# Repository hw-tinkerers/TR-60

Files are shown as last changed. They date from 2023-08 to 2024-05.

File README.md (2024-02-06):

# TR-60
TR-60 is a 60% custom mechanical keyboard PCB that is inspired by the  [bakeneko](https://github.com/kkatano/bakeneko-60) PCB but adds a couple of improvements to it.

1. TR-60 adds BLE support to the PCB so that it can be used wirelessly.
2. Add tray mount compatible holes to be used with keyboard cases like [Salvation](https://ilumkb.com/products/wilba-tech-salvation-keyboard)

TR-60 stands for typewriter-60.

The repository contains the KICAD files of the keyboard PCB design with an nRF chip and this PCB is one of the first PCB to be built around the nRF52840 bare chip and not around any module.

<strong>Front View (Rendering)</strong>

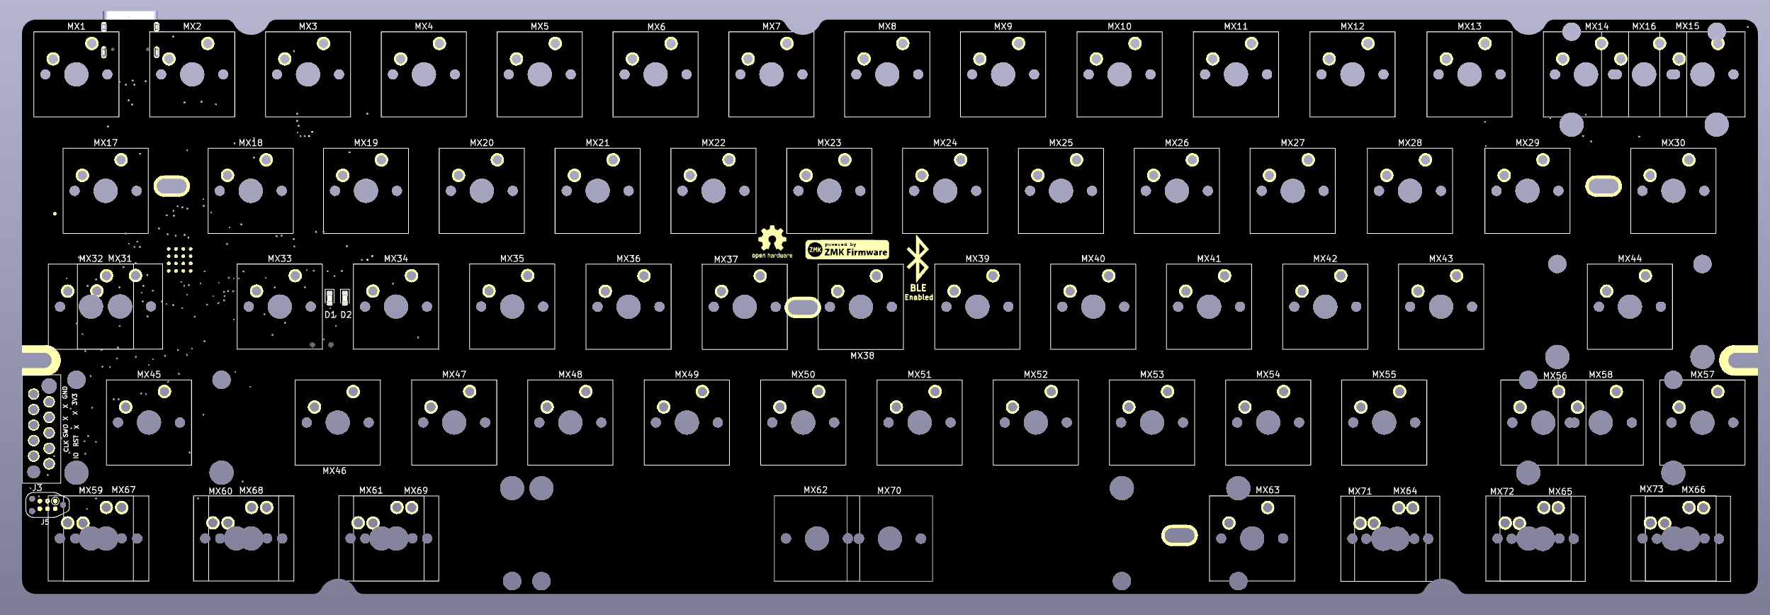
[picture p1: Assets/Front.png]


<strong>Back View (Rendering)</strong>

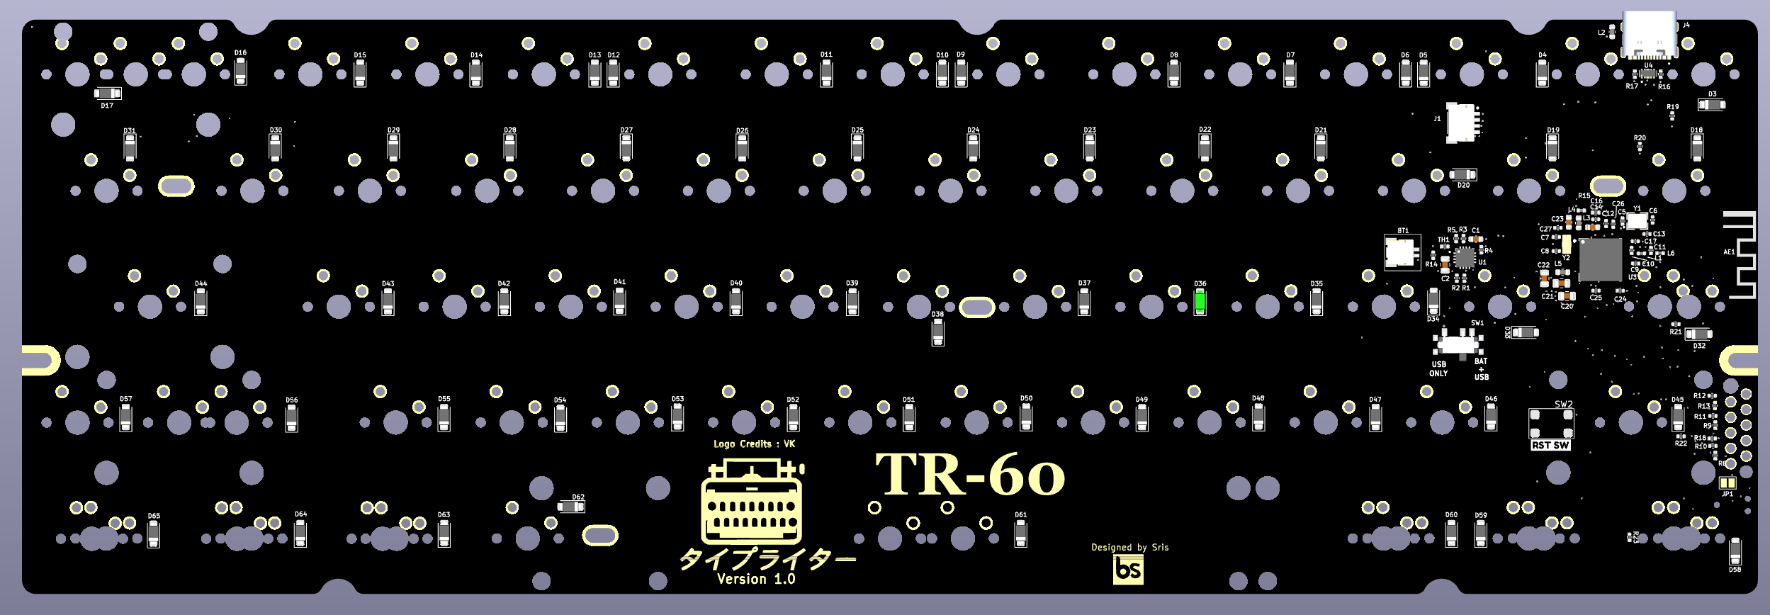
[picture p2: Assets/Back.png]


<strong>Front View of PCB</strong>.

plot

<strong>Back View of PCB</strong>.

plot

<strong>Front View fully assembled with keycaps</strong>.

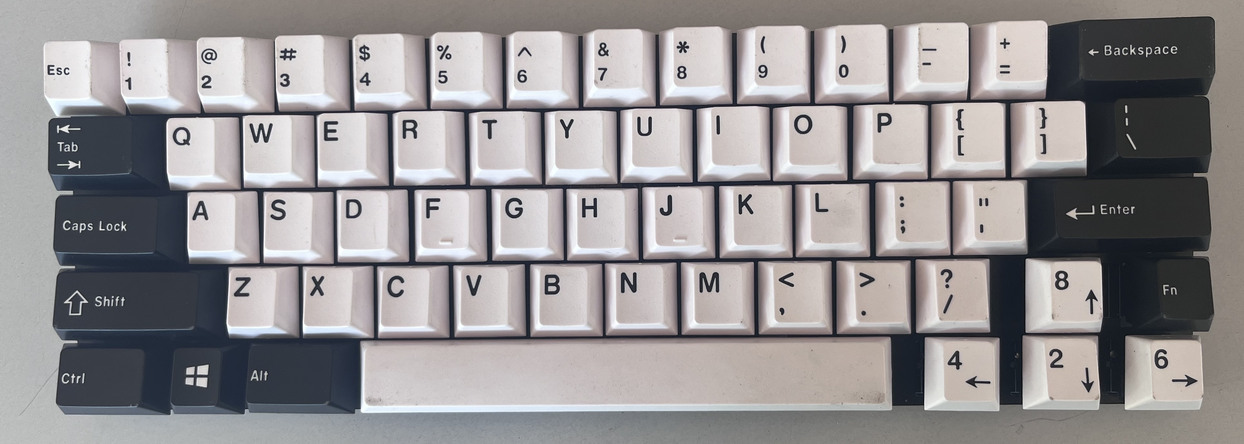
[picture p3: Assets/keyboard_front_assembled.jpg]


<strong>Back View fully assembled with battery</strong>.

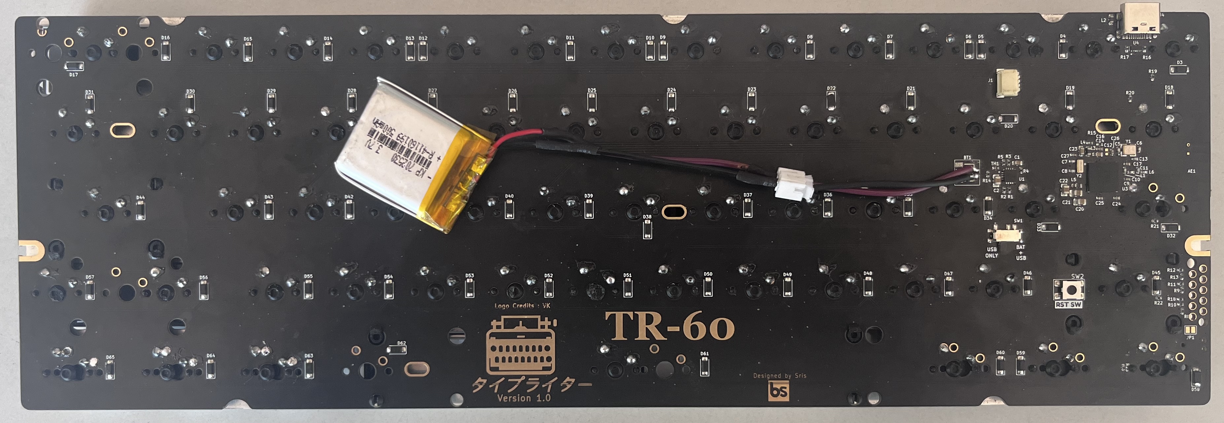
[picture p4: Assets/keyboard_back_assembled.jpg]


<strong>Fully assembled with Bakeneko case</strong>.

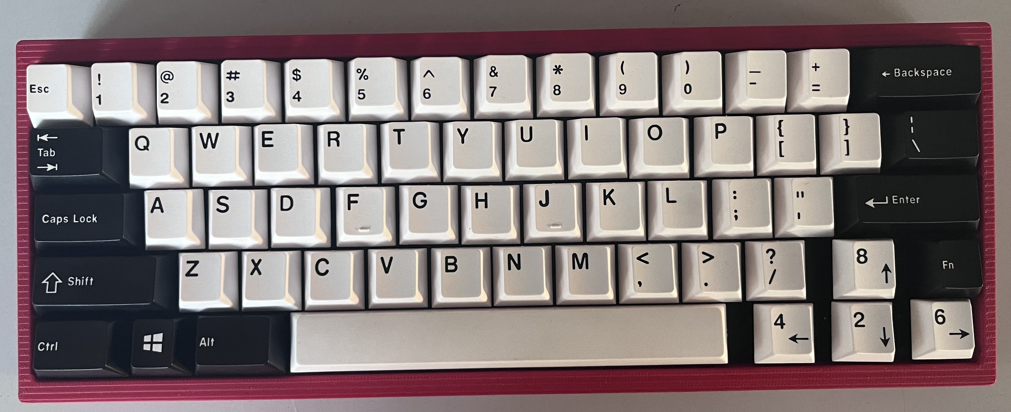
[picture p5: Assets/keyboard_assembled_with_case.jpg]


The PCB is designed in such a way that is compatible with both nRF52840 and nRF52833 MCUs as they have the same pinouts and the NC pins on nRF53833 are being used in nRF52840 making it compatible with both MCUs to mitigate supply shortage problems.

The PCB has a board antenna for BLE and an onboard charger chip BQ24075 (also compatible with BQ24073 and BQ24074) with a JST (1mm) connector for lipo battery (But the 1mm JST connector is non-conventional and will be changed to a more mainstream connector with 2.54mm pitch with which most lipo batteries are shipped). A lipo battery of 200-1000mAh can be used with the PCB. (Note: Tested only with 300mAH battery, but up to 1000mAH should not be a problem. But do it at your own risk)

The PCB has a SWD 10-pin debug connector compatible with [tag-connect](https://www.tag-connect.com/product/tc2050-idc-nl-050-all) 10-pin debug connector for flashing firmware.
The board also supports an Adafruit-UF2 bootloader to upload firmware through the USB type-C connector (If a PCB is bought from us). You can find how to build and flash the UF2 bootloader to the board in an upcoming tutorial. (still under making)

You can also order your PCB from JLC PCB with the Gerber and BOM files provided in the repository in the production folder. The video guide on how to order from JLC will be up soon.

The board supports [ZMK](https://zmk.dev/) firmware for USB and BLE connectivity. The hardware definition for the nRF52 chip is written and the guide to customize the keymap to customize the keys for the keyboard can be found below. 

The firmware can be built directly on GitHub using GitHub actions and also a local toolchain can be set up on your computer to build firmware. Both the links can be found below.

1. [Local Toolchain setup](https://github.com/hw-tinkerers/zmk)
2. [Github Actions](https://github.com/hw-tinkerers/tr60-zmk-config)

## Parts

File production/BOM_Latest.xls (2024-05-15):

Designator | Footprint | Qty | Value | LCSC Part Number | MFR PN
BT1 | keyboard:JST-2-pin | 1 | Lipo cell | C160402 | SM02B-SRSS-TB(LF)(SN)
C1, C14, C23 | keyboard:C_0603_1608Metric | 3 | 1uF | C1592 | CL10A105KO8NNNC
C2, C20, C21, C22 | keyboard:C_0805_2012Metric | 4 | 4u7F | C1779 | CL21A475KAQNNNE
C5, C6, C7, C8 | keyboard:C_0402_1005Metric | 4 | 8pF | C962144 | AC0402CRNPO9BN8R0
C9 | keyboard:C_0402_1005Metric | 1 | 820pF | C107031 | CC0402KRX7R9BB821
C10 | keyboard:C_0402_1005Metric | 1 | 1pF | C309455 | CC0402BRNPO9BN1R0
C11 | keyboard:C_0402_1005Metric | 1 | 1.2pF | C327292 | CC0402BRNPO9BN1R2
C13 | keyboard:C_0402_1005Metric | 1 | 100pF | C106200 | CC0402JRNPO9BN101
C16, C17, C24, C25, C26, C27 | keyboard:C_0402_1005Metric | 6 | 100nF | C1525 | CL05B104KO5NNNC
D1 | keyboard:LED_0603_1608Metric | 1 | LED | C965799 | XL-1608SURC-06
D2 | keyboard:LED_0603_1608Metric | 1 | LED | C193191 | ORH-B36G
D3, D4, D5, D6, D7, D8, D9, D10, D11, D12, D13, D14, D15, D16, D17, D18, D19, D20, D21, D22, D23, D24, D25, D26, D27, D28, D29, D30, D31, D32, D33, D34, D35, D36, D37, D38, D39, D40, D41, D42, D43, D44, D45, D46, D47, D48, D49, D50, D51, D52, D53, D54, D55, D56, D57, D58, D59, D60, D61, D62, D63, D64, D65 | keyboard:D_SOD-123 | 63 | 1N4148W | C81598 | 1N4148W
J1 | keyboard:JST-4-pin | 1 | JST-4-pin | C160404 | SM04B-SRSS-TB(LF)(SN)
J4 | keyboard:tyye_c_connector | 1 | TYPE-C-31-M12_13 | C165948 | TYPE-C-31-M-12
L1 | keyboard:L_0402_1005Metric | 1 | 4.7nH | C136252 | MLK1005S4N7ST000
L2 | keyboard:L_0603_1608Metric | 1 | 60R@100MHz | C307775 | MPZ1608S600ATDH5
L3, L5 | keyboard:L_0603_1608Metric | 2 | 10uH | C3911082 | LQM18DZ100M70L
L4 | keyboard:L_0402_1005Metric | 1 | 15nH | C86059 | LQG15HS15NJ02D
L6 | keyboard:L_0402_1005Metric | 1 | 2.2nH | C5201668 | BSCH001005052N2SCS
R1, R2, R3, R4 | keyboard:R_0402_1005Metric | 4 | 1k2 | C138040 | RC0402FR-071K2L
R5, R16, R17 | keyboard:R_0402_1005Metric | 3 | 5k1 | C105872 | RC0402FR-075K1L
R8, R9, R13, R14,R15, R18 | keyboard:R_0402_1005Metric | 6 | 10k | C60490 | RC0402FR-0710KL
R19, R20, R21, R22, R23 | keyboard:R_0402_1005Metric | 5 | 0E | C346504 | HCJ0402ZT0R00
R10, R11, R12 | keyboard:R_0402_1005Metric | 3 | 22E | C114765 | RC0402FR-0722RL
SW1 | keyboard:SPDT | 1 | MK-12C02-G025 | C778186 | MK-12C02-G025
SW2 | keyboard:RST_SW | 1 | Reset Switch | C388640 | TS-1127-C
TH1 | keyboard:R_0402_1005Metric | 1 | 10k | C95939 | SDNT1005X103F3950FTF
U1 | keyboard:QFN-16 | 1 | BQ24073RGTR | C15220 | BQ24073RGTR
U3 | keyboard:aqfn73 | 1 | nRF52840-QIAA-R | C190794 | nRF52840-QIAA-R
U4 | keyboard:USON-10 | 1 | TPD4E05U06DQAR | C138714 | TPD4E05U06DQAR
Y1 | keyboard:SMD-4_crystal | 1 | 32MHz | C2149125 | 3TJ432000HYFBC
Y2 | keyboard:SMD-2_crystal | 1 | 32.768kHz | C97605 | SC-32S32.768kHz20PPM9pF

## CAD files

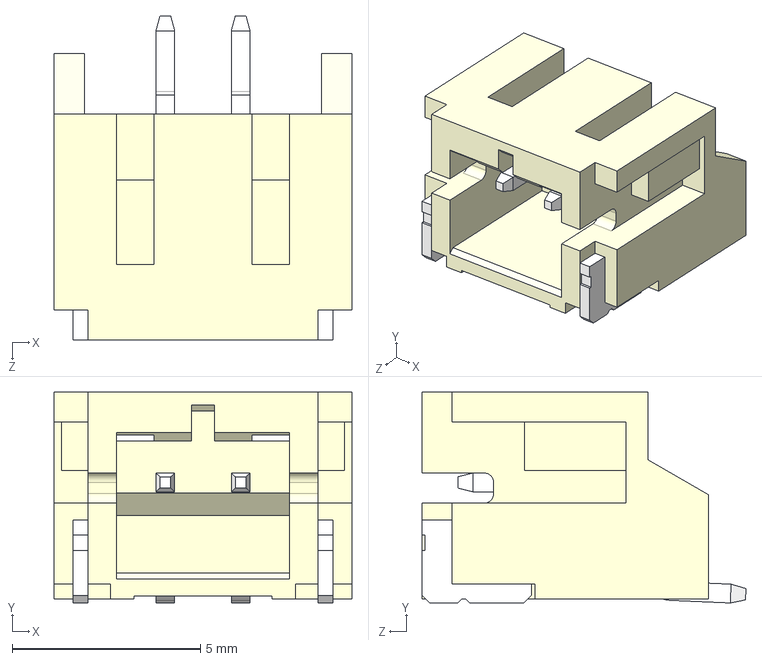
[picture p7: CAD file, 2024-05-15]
3d-models/JST-2pin.STEP
7.90 x 5.60 x 8.60 mm

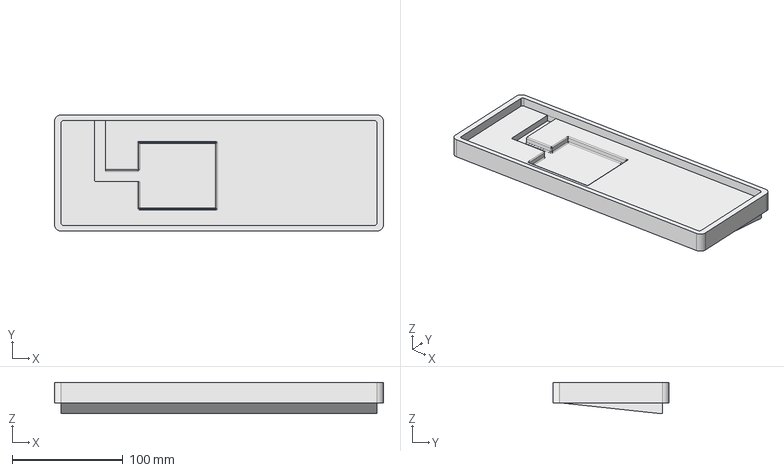
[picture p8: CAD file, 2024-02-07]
Keyboard_60-Body.step
297.0 x 105.0 x 28.4 mm

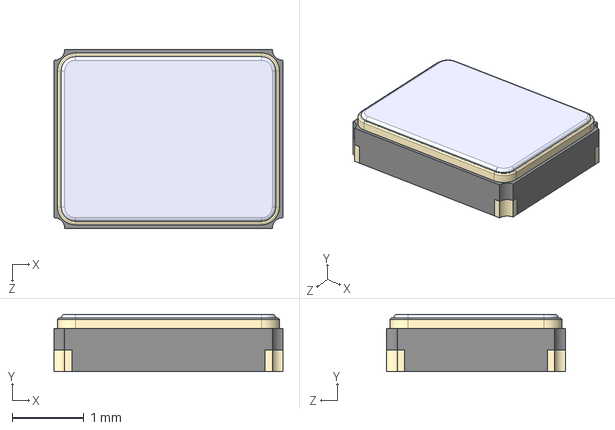
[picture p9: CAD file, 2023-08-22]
3d-models/SMD-4_crystal.STEP
3.20 x 0.8 x 2.50 mm

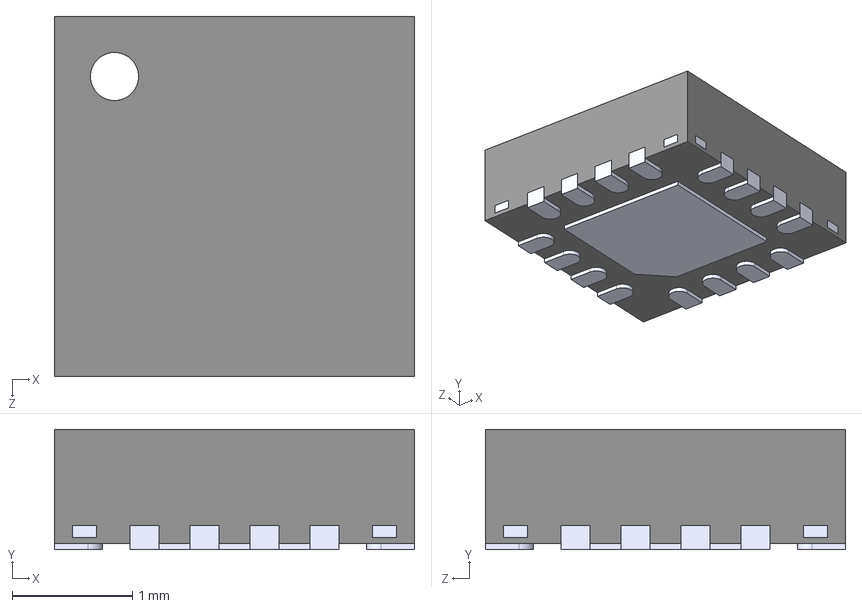
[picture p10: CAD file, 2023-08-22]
3d-models/VQFN-16.STEP
3.00 x 1.00 x 3.00 mm

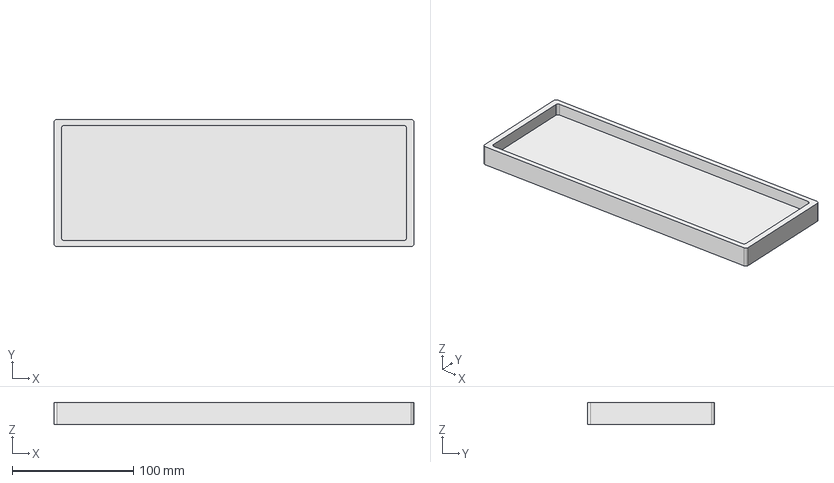
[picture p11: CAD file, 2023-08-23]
TR-60.FCStd
297.0 x 105.0 x 18.5 mm

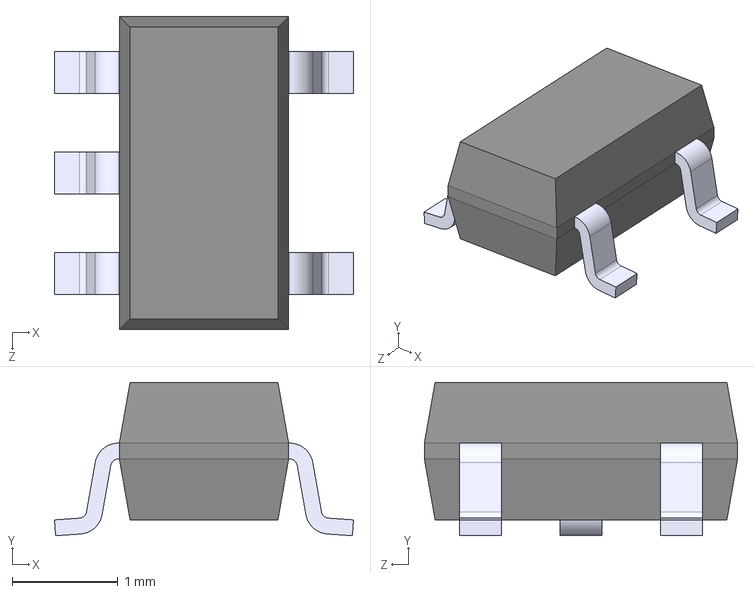
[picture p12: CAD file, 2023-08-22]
3d-models/SOT-23-5.STEP
2.82 x 1.45 x 2.96 mm

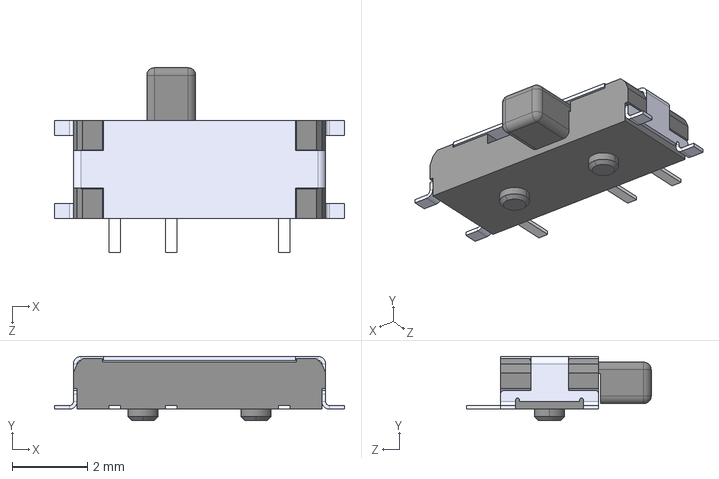
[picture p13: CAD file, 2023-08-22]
3d-models/SPDT.step
7.70 x 1.70 x 4.90 mm

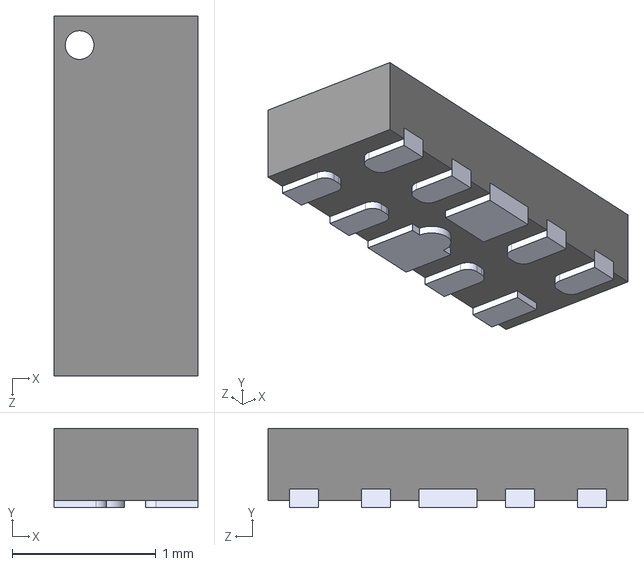
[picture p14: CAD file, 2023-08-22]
3d-models/USON-10.STEP
1.00 x 0.55 x 2.50 mm

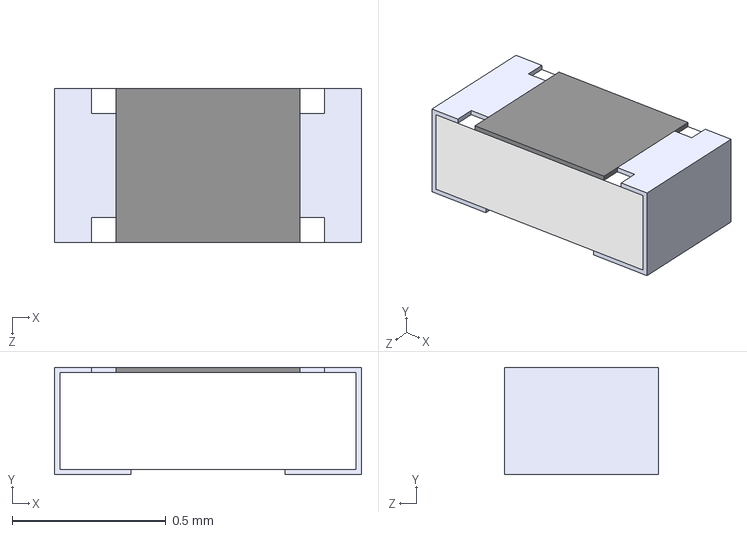
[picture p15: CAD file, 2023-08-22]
3d-models/R_0402.STEP
1 x 0.35 x 0.5 mm

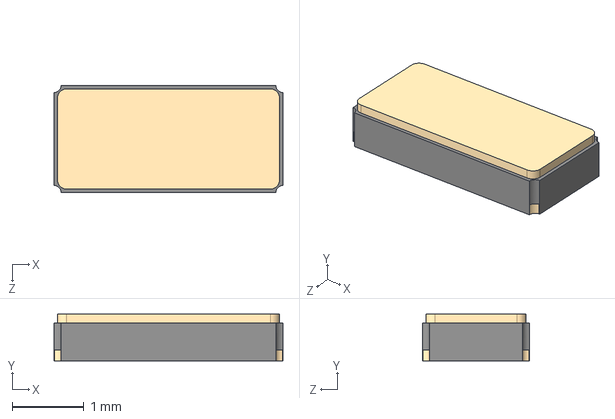
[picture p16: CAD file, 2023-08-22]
3d-models/SMD-2.step
3.20 x 0.65 x 1.50 mm

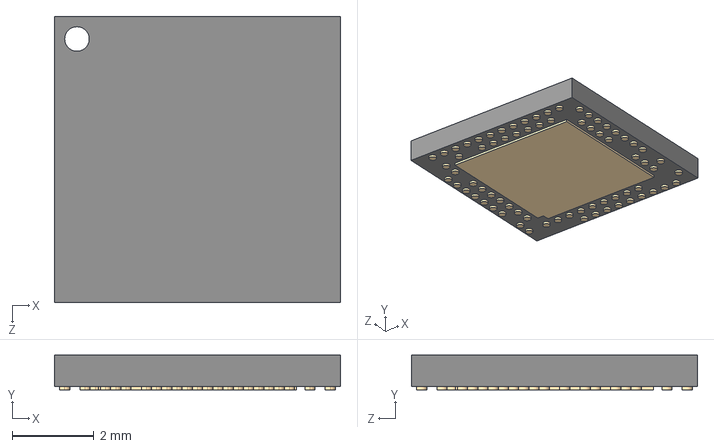
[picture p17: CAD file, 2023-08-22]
3d-models/AQFN-73.STEP
7.00 x 0.85 x 7.00 mm

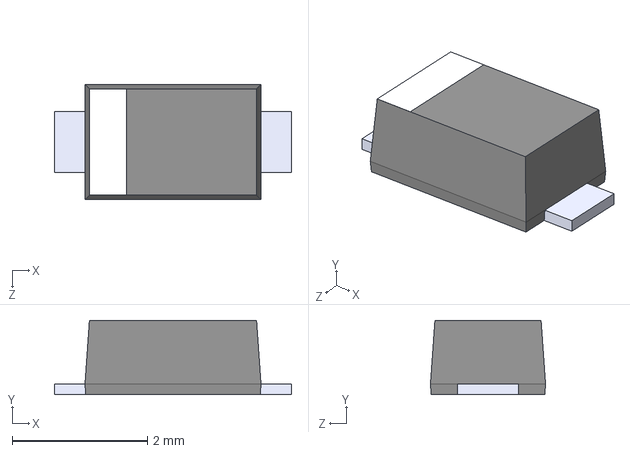
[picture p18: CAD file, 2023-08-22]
3d-models/SOD-123.STEP
3.50 x 1.10 x 1.70 mm

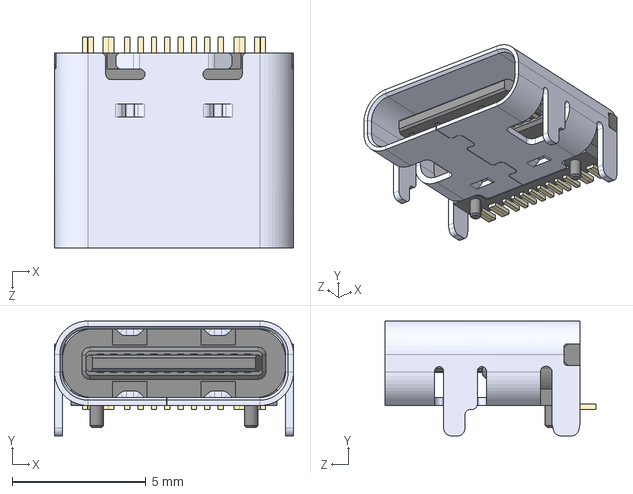
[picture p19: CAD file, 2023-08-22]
3d-models/type_c_connector.STEP
8.94 x 4.30 x 7.90 mm

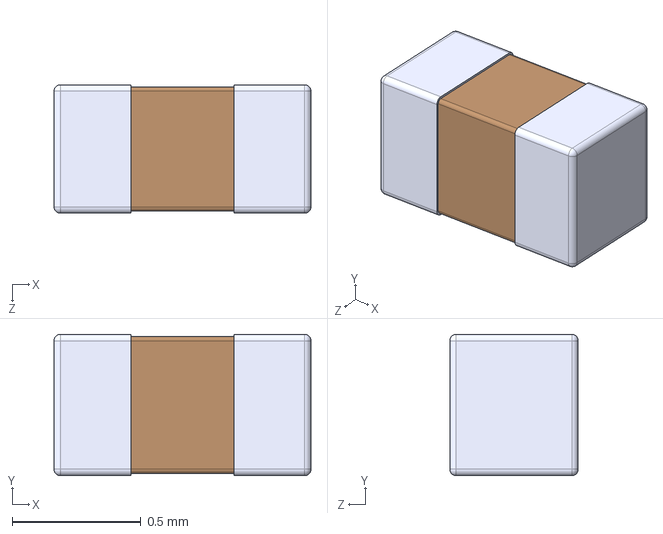
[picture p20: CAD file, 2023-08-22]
3d-models/C_0402.STEP
1.00 x 0.55 x 0.5 mm

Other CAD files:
Keyboard_60.FCStd
3d-models/C_0805.STEP
3d-models/JST-4pin.STEP
3d-models/C_0603.STEP
3d-models/LED_0603.STEP

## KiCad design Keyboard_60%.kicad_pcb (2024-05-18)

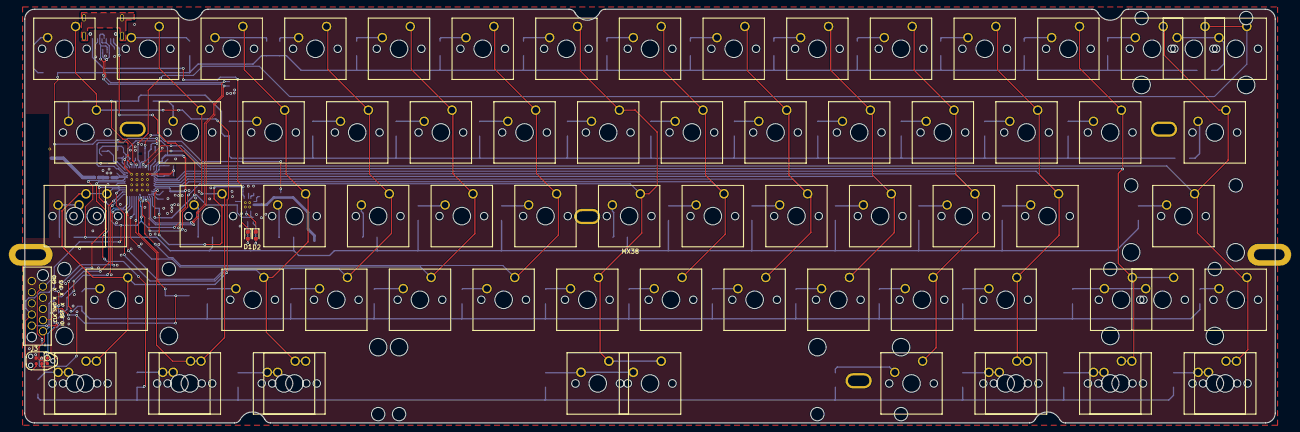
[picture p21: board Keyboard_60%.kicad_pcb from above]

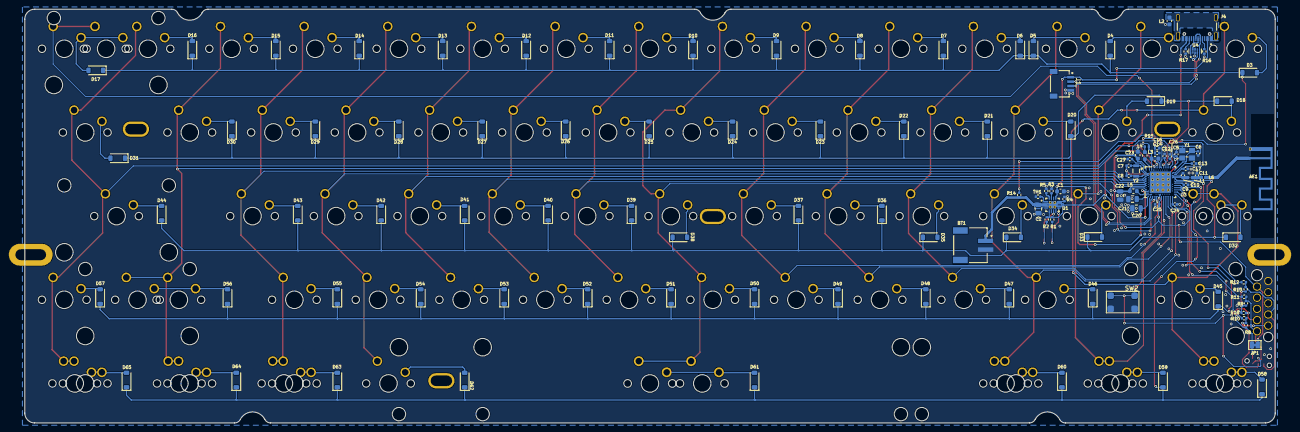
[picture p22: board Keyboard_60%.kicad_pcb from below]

Board: 2 copper layers, 284.7 x 94.2 mm, 200 parts (119 on the bottom side), 126 nets.

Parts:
AE1: Antenna_Shield; BLE_ANTENNA
BT1: Lipo cell; JST-2-pin
C1, C14, C23: 1uF; C_0603_1608Metric
C2, C20, C21, C22: 4u7F; C_0805_2012Metric
C5, C6, C7, C8: 8pF; C_0402_1005Metric
C9: 820pF; C_0402_1005Metric
C10: 1pF; C_0402_1005Metric
C11: 1.2pF; C_0402_1005Metric
C12: DNP; C_0402_1005Metric
C13: 100pF; C_0402_1005Metric
C16, C17, C24, C25, C26, C27: 100nF; C_0402_1005Metric
D1, D2: LED; LED_0603_1608Metric
D3, D4, D5, D6, D7, D8, D9, D10, D11, D12, D13, D14, D15, D16, D17, D18, D19, D20, D21, D22, D23, D24, D25, D26, D27, D28, D29, D30, D31, D32, D33, D34, D35, D36, D37, D38, D39, D40, D41, D42, D43, D44, D45, D46, D47, D48, D49, D50, D51, D52, D53, D54, D55, D56, D57, D58, D59, D60, D61, D62, D63, D64, D65: 1N4148W; D_SOD-123
J1: JST-4-pin
J3: Prog_conn; DB_CONN
J4: TYPE-C-31-M12_13; tyye_c_connector
J5: Tag connect TC2030-CTX; TC2030-IDC-NL
JP1: SolderJumper; SolderBridge
L1: 4.7nH; L_0402_1005Metric
L2: 60R@100MHz; L_0603_1608Metric
L3, L5: 10uH; L_0603_1608Metric
L4: 15nH; L_0402_1005Metric
L6: 2.2nH; L_0402_1005Metric
MX1, MX2, MX3, MX4, MX5, MX6, MX7, MX8, MX9, MX10, MX11, MX12, MX13, MX14, MX15, MX18, MX19, MX20, MX21, MX22, MX23, MX24, MX25, MX26, MX27, MX28, MX29, MX33, MX34, MX35, MX36, MX37, MX38, MX39, MX40, MX41, MX42, MX43, MX46, MX47, MX48, MX49, MX50, MX51, MX52, MX53, MX54, MX55, MX57, MX68, MX72: 1u; SW_Cherry_MX_1.00u_PCB
MX16: 2u; SW_Cherry_MX_2.00u_PCB
MX17, MX30, MX67, MX69, MX71, MX73: 1.5u; SW_Cherry_MX_1.50u_PCB
MX31, MX56: 1.75u; SW_Cherry_MX_1.75u_PCB
MX32, MX59, MX60, MX61, MX63, MX64, MX65, MX66: 1.25u; SW_Cherry_MX_1.25u_PCB
MX44, MX45: 2.25u; SW_Cherry_MX_2.25u_PCB
MX58: 2.75u; SW_Cherry_MX_2.75u_PCB
MX62: 6.25u; SW_Cherry_MX_6.25u_PCB
MX70: 7u; SW_Cherry_MX_7.00u_PCB
R1, R2, R4: 1k2; R_0402_1005Metric
R3: 8k2; R_0402_1005Metric
R5, R16, R17: 5k1; R_0402_1005Metric
R8, R9, R13, R14, R15, R18: 10k; R_0402_1005Metric
R10, R11, R12: 22E; R_0402_1005Metric
S1: Open Hardware; OSHW-Logo
S2: Keybaord_outline_edgecuts
S3: BLE-symbol
S4: ZMK_logo
SW2: Reset Switch; RST_SW
TH1: 10k; R_0402_1005Metric
U1: BQ24074RGTR; QFN-16
U3: nRF52840-QIAA-R/nRF52833-QIAA-R; aqfn73
U4: TPD4E05U06DQAR; USON-10
Y1: 32MHz; SMD-4_crystal
Y2: 32.768kHz; SMD-2_crystal

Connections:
/ANT_FEED: AE1.1 (A), L6.2
/COL0: MX1.2 (B), MX17.2 (B), MX31.2 (B), MX32.2 (B), MX45.2 (B), MX59.2 (B), MX67.2 (B), U3.U24 (P1.04)
/COL1: MX2.2 (B), MX18.2 (B), MX33.2 (B), MX60.2 (B), MX68.2 (B), U3.AD16 (P0.20)
/COL2: MX3.2 (B), MX19.2 (B), MX34.2 (B), MX46.2 (B), MX61.2 (B), MX69.2 (B), U3.W24 (P1.02)
/COL3: MX4.2 (B), MX20.2 (B), MX35.2 (B), MX47.2 (B), U3.AD20 (P0.24)
/COL4: MX5.2 (B), MX21.2 (B), MX36.2 (B), MX48.2 (B), U3.AD18 (P0.22)
/COL5: MX6.2 (B), MX22.2 (B), MX37.2 (B), MX49.2 (B), U3.AD10 (P0.15)
/COL6: MX7.2 (B), MX23.2 (B), MX38.2 (B), MX50.2 (B), MX62.2 (B), MX70.2 (B), U3.AD8 (P0.13)
/COL7: MX8.2 (B), MX24.2 (B), MX39.2 (B), MX51.2 (B), U3.R1 (P1.09/TRACEDATA3)
/COL8: MX9.2 (B), MX25.2 (B), MX40.2 (B), MX52.2 (B), U3.N1 (P0.08)
/COL9: MX10.2 (B), MX26.2 (B), MX41.2 (B), MX53.2 (B), U3.L1 (P0.06)
/COL10: MX11.2 (B), MX27.2 (B), MX42.2 (B), MX54.2 (B), MX63.2 (B), U3.J1 (P0.04/AIN2)
/COL11: MX12.2 (B), MX28.2 (B), MX43.2 (B), MX55.2 (B), MX64.2 (B), MX71.2 (B), U3.G1 (P0.26)
/COL12: MX13.2 (B), MX29.2 (B), MX56.2 (B), MX58.2 (B), MX65.2 (B), MX72.2 (B), U3.A8 (P0.31/AIN7)
/COL13: MX14.2 (B), MX30.2 (B), MX44.2 (B), MX57.2 (B), MX66.2 (B), MX73.2 (B), U3.A10 (P0.29/AIN5)
/COL14: MX15.2 (B), MX16.2 (B), U3.A14 (P1.15)
/DB_SWDCLK: J3.1, J5.4, R8.1, R10.1
/DB_SWDIO: J3.6, J5.2, R9.1, R11.1
/DB_SWO: J3.2, J5.6, R12.1, R13.1
/ROW0: D3.1 (K), D4.1 (K), D5.1 (K), D6.1 (K), D7.1 (K), D8.1 (K), D9.1 (K), D10.1 (K), D11.1 (K), D12.1 (K), D13.1 (K), D14.1 (K), D15.1 (K), D16.1 (K), D17.1 (K), U3.A20 (P1.10)
/ROW1: D18.1 (K), D19.1 (K), D20.1 (K), D21.1 (K), D22.1 (K), D23.1 (K), D24.1 (K), D25.1 (K), D26.1 (K), D27.1 (K), D28.1 (K), D29.1 (K), D30.1 (K), D31.1 (K), U3.A16 (P1.13)
/ROW2: D32.1 (K), D33.1 (K), D34.1 (K), D35.1 (K), D36.1 (K), D37.1 (K), D38.1 (K), D39.1 (K), D40.1 (K), D41.1 (K), D42.1 (K), D43.1 (K), D44.1 (K), U3.J24 (P0.10/NFC2)
/ROW3: D45.1 (K), D46.1 (K), D47.1 (K), D48.1 (K), D49.1 (K), D50.1 (K), D51.1 (K), D52.1 (K), D53.1 (K), D54.1 (K), D55.1 (K), D56.1 (K), D57.1 (K), U3.L24 (P0.09/NFC1)
/ROW4: D58.1 (K), D59.1 (K), D60.1 (K), D61.1 (K), D62.1 (K), D63.1 (K), D64.1 (K), D65.1 (K), U3.R24 (P1.06)
/USB and Power management/V_BATT: BT1.1 (+), C2.1, R14.2, U1.2 (BAT_2), U1.3 (BAT_3)
/USB_D+: J1.3, J4.A6 (D+), J4.B6 (D+), U3.AD6 (D+), U4.1 (IO1), U4.4 (D2+), U4.7 (NC), U4.10 (NC)
/USB_D-: J1.2, J4.A7 (D-), J4.B7 (D-), U3.AD4 (D-), U4.2 (IO2), U4.5 (D2-), U4.6 (NC), U4.9 (NC)
/VBATT_nRF: C16.1, R14.1, R15.2, U3.A12 (P0.02/AIN0)
/VBUS: C1.1, C20.1, J1.1, J4.A4 (VBUS), U1.13 (IN), U3.AD2 (VBUS)
/VDDH: J4.B4 (VBUS), R1.1, R2.1, U1.5 (EN2), U1.10 (OUT_10), U1.11 (OUT_11), U3.Y2 (VDDH)
/VDD_nRF: C22.1, C23.2, C24.1, C25.1, C26.1, J3.10, JP1.1 (A), L5.1, U3.A22 (VDD), U3.AD14 (VDD), U3.AD23 (VDD), U3.B1 (VDD), U3.W1 (VDD)
/~nReset: J3.7, J5.3, R18.1, SW2.1, U3.AC13 (P0.18/NRESET), U3.AD12 (P0.17)
GND: AE1.2 (Shield), BT1.2 (-), C1.2, C2.2, C5.1, C6.1, C7.1, C8.1, C9.1, C10.2, C11.2, C12.1, C13.1, C14.2, C16.2, C17.1, C20.2, C21.2, C22.2, C23.1, C24.2, C25.2, C26.2, C27.1, J1.4, J3.5, J4.A1 (GND), J4.B1 (GND), J5.5, L2.1, R3.1, R4.1, R5.2, R15.1, R16.2, R17.2, SW2.2, TH1.2, U1.4 (~CE), U1.6 (EN1), U1.8 (VSS), U1.17 (EXP), U3.74 (VSS), U3.74_1 (VSS), U3.74_2 (VSS), U3.74_3 (VSS), U3.74_4 (VSS), U3.74_5 (VSS), U3.74_6 (VSS), U3.74_7 (VSS), U3.74_8 (VSS), U3.74_9 (VSS), U3.74_10 (VSS), U3.74_11 (VSS), U3.74_12 (VSS), U3.74_13 (VSS), U3.74_14 (VSS), U3.74_15 (VSS), U3.74_16 (VSS), U3.B7 (VSS), U3.F23 (VSS_PA), U4.3 (GND), U4.8 (GND), Y1.2, Y1.4
GNDPWR: J4.S (SHIELD), L2.2
unnamed: C11.1, L1.2, L6.1
unnamed: D1.2 (A), R1.2
unnamed: D1.1 (K), U1.9 (~CHG)
unnamed: D2.2 (A), R2.2
unnamed: D2.1 (K), U1.7 (~PGOOD)
unnamed: D3.2 (A), MX1.1 (A)
unnamed: D4.2 (A), MX2.1 (A)
unnamed: D5.2 (A), MX3.1 (A)
unnamed: D6.2 (A), MX4.1 (A)
unnamed: D7.2 (A), MX5.1 (A)
unnamed: D8.2 (A), MX6.1 (A)
unnamed: D9.2 (A), MX7.1 (A)
unnamed: D10.2 (A), MX8.1 (A)
unnamed: D11.2 (A), MX9.1 (A)
unnamed: D12.2 (A), MX10.1 (A)
unnamed: D13.2 (A), MX11.1 (A)
unnamed: D14.2 (A), MX12.1 (A)
unnamed: D15.2 (A), MX13.1 (A)
unnamed: D16.2 (A), MX14.1 (A)
unnamed: D17.2 (A), MX15.1 (A), MX16.1 (A)
unnamed: D18.2 (A), MX17.1 (A)
unnamed: D19.2 (A), MX18.1 (A)
unnamed: D20.2 (A), MX19.1 (A)
unnamed: D21.2 (A), MX20.1 (A)
unnamed: D22.2 (A), MX21.1 (A)
unnamed: D23.2 (A), MX22.1 (A)
unnamed: D24.2 (A), MX23.1 (A)
unnamed: D25.2 (A), MX24.1 (A)
unnamed: D26.2 (A), MX25.1 (A)
unnamed: D27.2 (A), MX26.1 (A)
unnamed: D28.2 (A), MX27.1 (A)
unnamed: D29.2 (A), MX28.1 (A)
unnamed: D30.2 (A), MX29.1 (A)
unnamed: D31.2 (A), MX30.1 (A)
unnamed: D32.2 (A), MX31.1 (A), MX32.1 (A)
unnamed: D33.2 (A), MX33.1 (A)
unnamed: D34.2 (A), MX34.1 (A)
unnamed: D35.2 (A), MX35.1 (A)
unnamed: D36.2 (A), MX36.1 (A)
unnamed: D37.2 (A), MX37.1 (A)
unnamed: D38.2 (A), MX38.1 (A)
unnamed: D39.2 (A), MX39.1 (A)
unnamed: D40.2 (A), MX40.1 (A)
unnamed: D41.2 (A), MX41.1 (A)
unnamed: D42.2 (A), MX42.1 (A)
unnamed: D43.2 (A), MX43.1 (A)
unnamed: D44.2 (A), MX44.1 (A)
unnamed: D45.2 (A), MX45.1 (A)
unnamed: D46.2 (A), MX46.1 (A)
unnamed: D47.2 (A), MX47.1 (A)
unnamed: D48.2 (A), MX48.1 (A)
unnamed: D49.2 (A), MX49.1 (A)
unnamed: D50.2 (A), MX50.1 (A)
unnamed: D51.2 (A), MX51.1 (A)
unnamed: D52.2 (A), MX52.1 (A)
unnamed: D53.2 (A), MX53.1 (A)
unnamed: D54.2 (A), MX54.1 (A)
unnamed: D55.2 (A), MX55.1 (A)
unnamed: D56.2 (A), MX56.1 (A), MX58.1 (A)
unnamed: D57.2 (A), MX57.1 (A)
unnamed: D58.2 (A), MX59.1 (A), MX67.1 (A)
unnamed: D59.2 (A), MX60.1 (A), MX68.1 (A)
unnamed: D60.2 (A), MX61.1 (A), MX69.1 (A)
unnamed: D61.2 (A), MX62.1 (A), MX70.1 (A)
unnamed: D62.2 (A), MX63.1 (A)
unnamed: D63.2 (A), MX64.1 (A), MX71.1 (A)
unnamed: D64.2 (A), MX65.1 (A), MX72.1 (A)
unnamed: D65.2 (A), MX66.1 (A), MX73.1 (A)
unnamed: J4.A5 (CC1), R16.1
unnamed: J4.B5 (CC2), R17.1
unnamed: J5.1, JP1.2 (B), R8.2, R9.2, R13.2, R18.2
unnamed: L3.1, L4.2
unnamed: R4.2, U1.12 (ILIM)
unnamed: R3.2, U1.16 (ISET)
unnamed: R5.1, U1.15 (ITERM)
unnamed: TH1.1, U1.1 (TS)
unnamed: C10.1, L1.1, U3.H23 (ANT)
unnamed: L3.2, U3.B3 (DCC)
unnamed: L5.2, U3.AB2 (DCCH)
unnamed: C27.2, U3.C1 (DEC1)
unnamed: C12.2, U3.A18 (DEC2)
unnamed: C13.2, U3.D23 (DEC3)
unnamed: C14.1, C17.2, L4.1, U3.B5 (DEC4), U3.E24 (DEC6)
unnamed: C9.2, U3.N24 (DEC5)
unnamed: C21.1, U3.AC5 (DECUSB)
unnamed: C7.2, U3.D2 (P0.00/XL1), Y2.1
unnamed: C8.2, U3.F2 (P0.01/XL2), Y2.2
unnamed: R12.2, U3.AD22 (P1.00/SWO)
unnamed: R10.2, U3.AA24 (SWDCLK)
unnamed: R11.2, U3.AC24 (SWDIO)
unnamed: C6.2, U3.B24 (XC1), Y1.3
unnamed: C5.2, U3.A23 (XC2), Y1.1

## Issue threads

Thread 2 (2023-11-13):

Series resistors for rows in key matrix to be changed to 0E.

hw-tinkerers, 2023-11-13:
There are 10k series current limiting resistors in rows for the key matrix due to which the 10k resistor acts as a voltage divider and cannot identify a key press. The issue can be easily solved by replacing the 10k resistor with 0E resistors on the PCB for this revision. The series resistors can be removed in next revision as they are not needed.

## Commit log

2023-08-22 Added kicad files for V1.0 of TR-60
    [AQFN-73.STEP, BOM_Latest.csv, BOM_Latest.xls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]
2023-08-23 Keyboard Case files
    Work in progress for Keyboard case files
    [TR-60.FCStd]
2023-11-15 Gerber changed
2024-01-31 Added pictures of assembled keyboard and corrected typos in README file
2024-02-07 Added keyboard case file
    [Keyboard_60-Body.step, Keyboard_60.FCStd]
2024-02-17 Finalized hardware Ver 1 release
    [Keyboard_60%.kicad_sch, USB_power.kicad_sch, switch_matrix.kicad_sch]
2024-04-15 Added instructions to pair unpair device
2024-05-15 Exported edge cuts as footprint and set grid origin
    [BOM_Latest.xls, JST-2pin.STEP, Keyboard_60%.kicad_pcb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]
2024-05-15 Completed routing for rows
    [Keyboard_60%.kicad_pcb]
2024-05-15 Completed routing for columns and rows for NRF
    [Keyboard_60%.kicad_pcb]
2024-05-15 Added charger circuit
    [Keyboard_60%.kicad_pcb]
2024-05-18 Solved all DRC and updated Versioning
    [Keyboard_60%.kicad_pcb, Keyboard_60%.kicad_sch]
